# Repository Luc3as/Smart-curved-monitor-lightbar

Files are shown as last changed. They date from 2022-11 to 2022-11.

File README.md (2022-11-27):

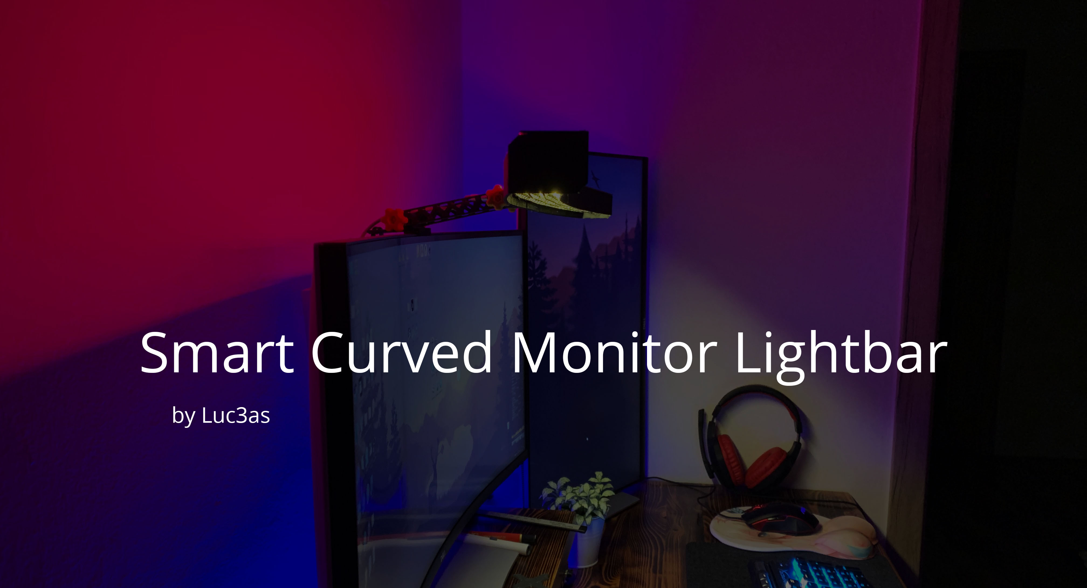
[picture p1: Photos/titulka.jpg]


## Idea behind this project

Custom made light bar, with easy connectivity and controllability from any home automation system. 
Integrated dual CCT light strip, to set just right color of light by time of day or type of task doing under the light. 
Backlight providing custom non disruptive mood light, with advanced effects possible thanks to individually addressable light strip. 
Everything powered from single USB-C 5V connector.

Universal attachment arms with adjustable height and angle for different monitor types.

## Designing the lightbar
Main goal here was to find a way and arrangement of led strip to provide light shining to desk, but without glaring into users’ eyes sitting behind the desk or casting light glares on monitor. I did some tests, measurements, came up with different lamp body designs, after few versions I came up with good solutions to satisfy those needs.  
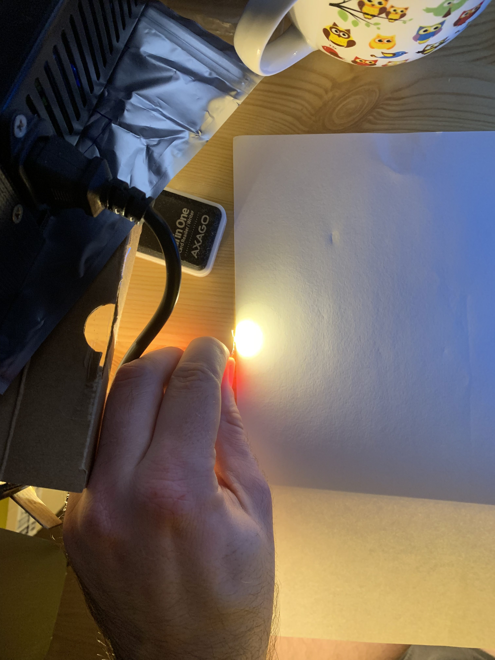
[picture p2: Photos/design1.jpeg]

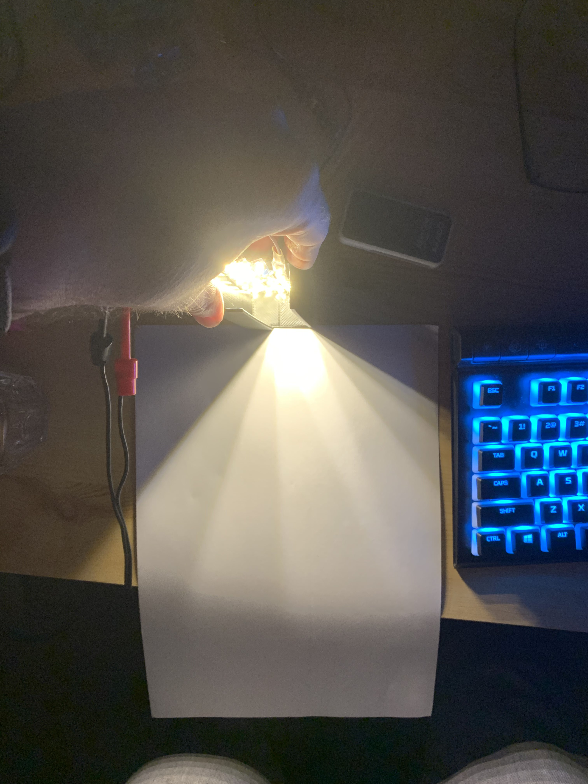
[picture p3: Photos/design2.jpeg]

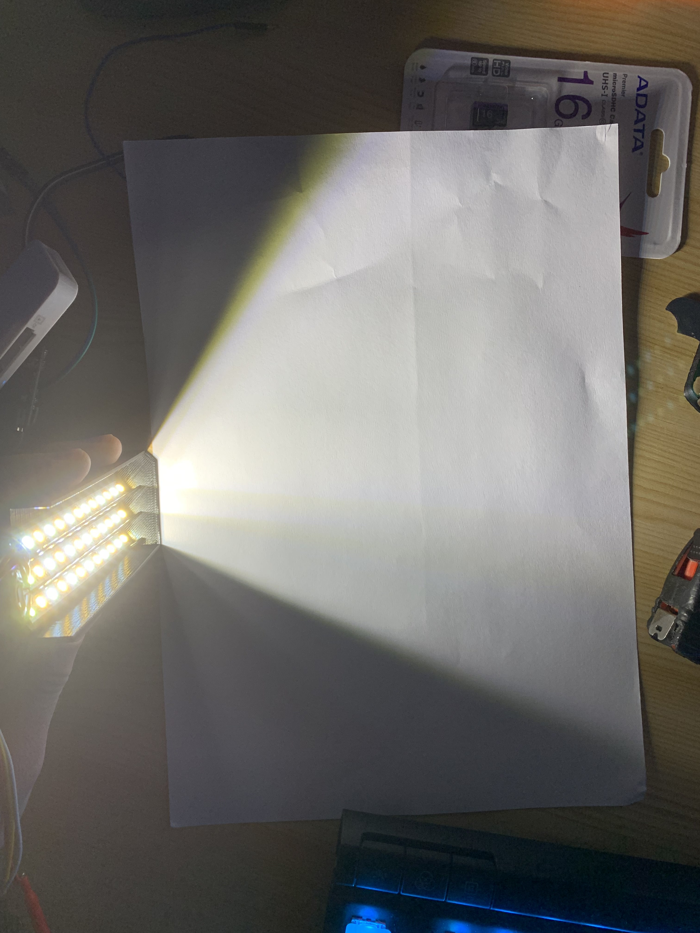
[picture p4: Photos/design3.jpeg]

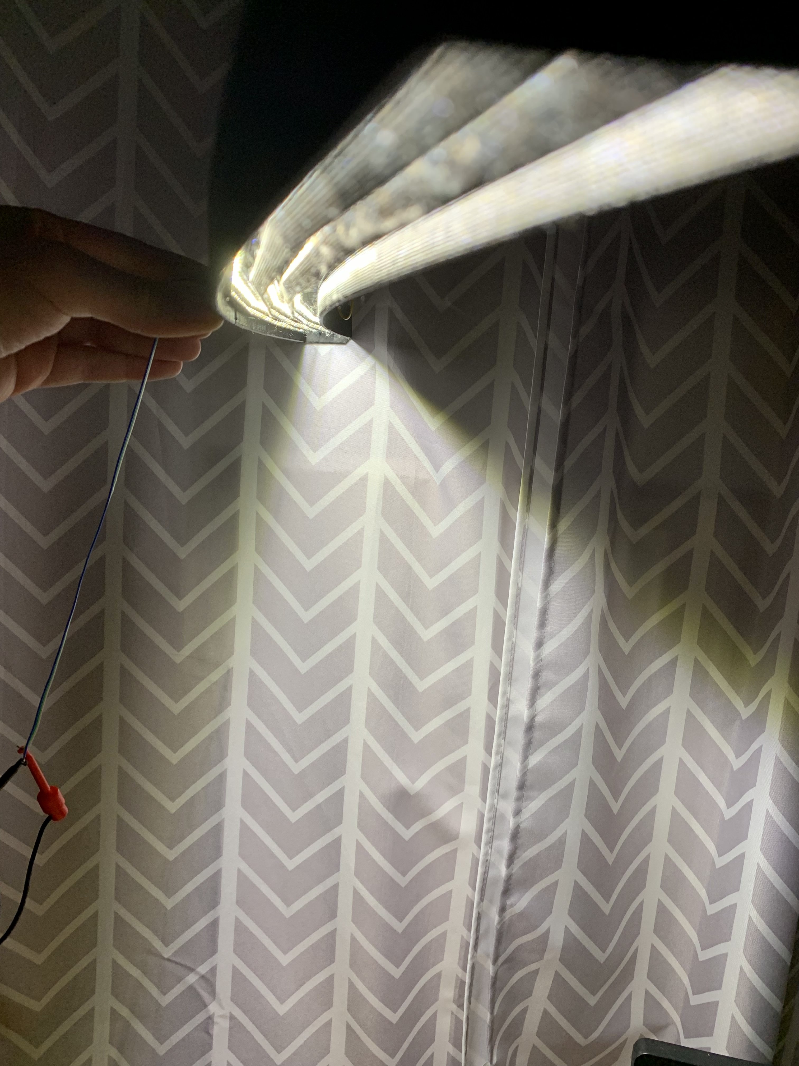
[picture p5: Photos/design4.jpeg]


## Printing and assembling

As material I picked PETG, but PLA would be OK too.

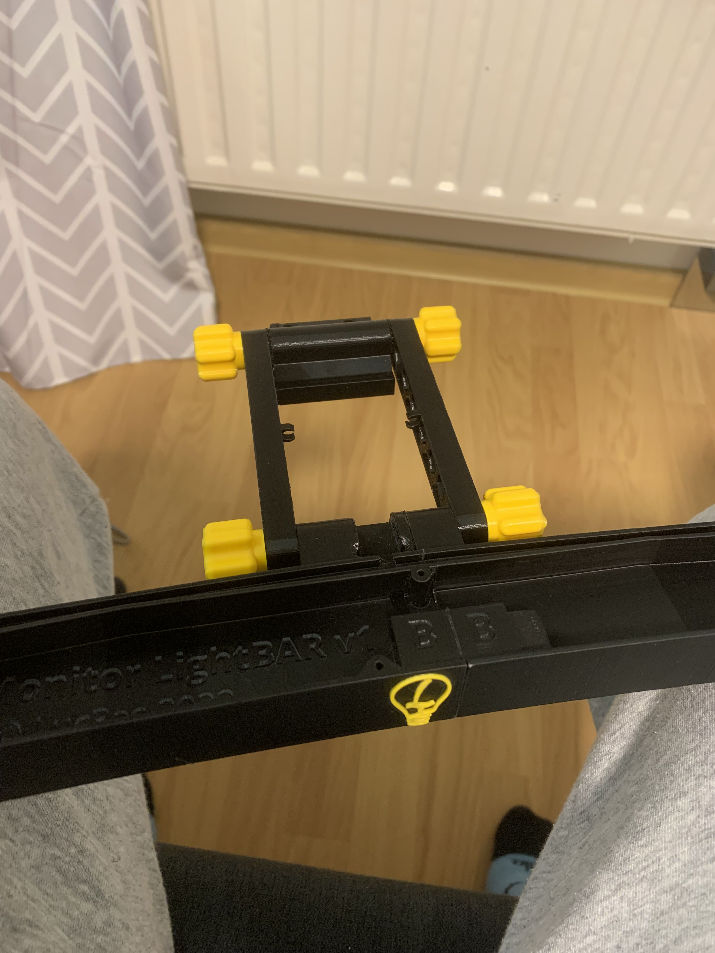
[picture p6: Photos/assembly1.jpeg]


Parts was designed to fit on standard size 3D printer

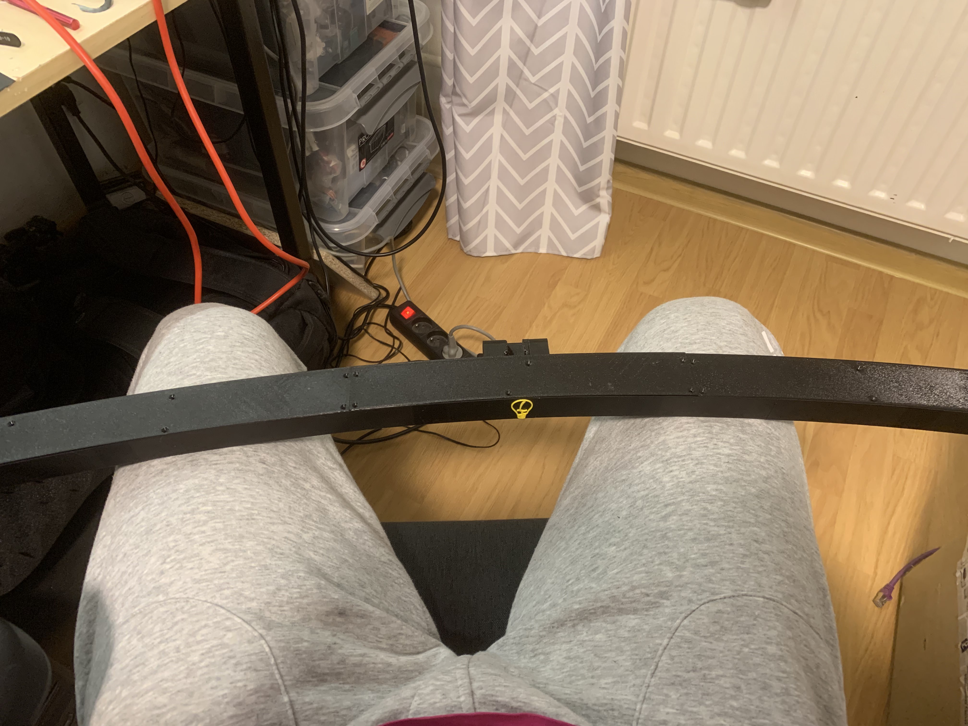
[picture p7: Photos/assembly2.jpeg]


Parts which will hold some mechanical load was designed for mechanical 3D inserts. 

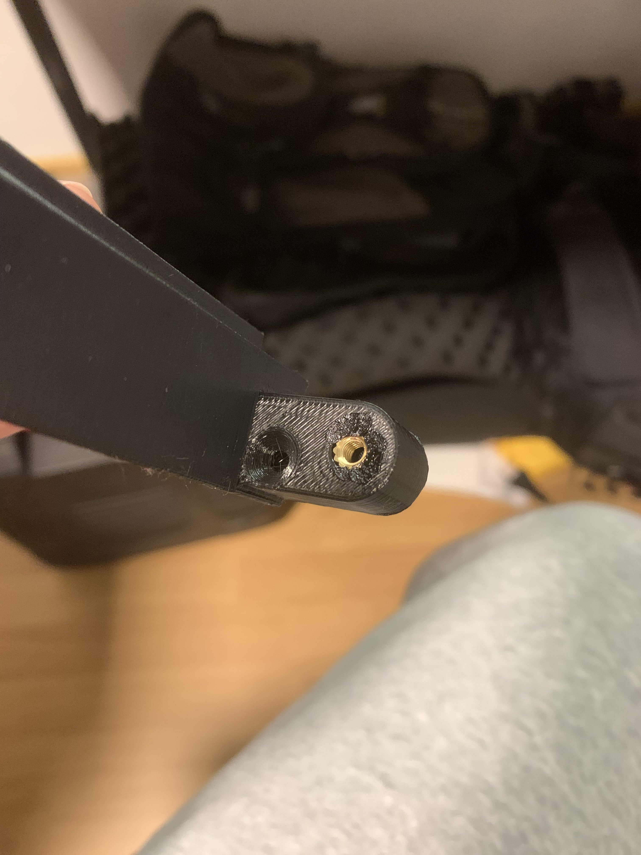
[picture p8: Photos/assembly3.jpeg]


## LEDs and electronics

I used dual CCT light strip powered by 5V, and WS2812b LED strip for backlight. Electronics is very simplistic, main controller is Wemos D1 mini, and 5V USB-C female connector board. There is no physical button for controlling the light as I will use home automation to control it. However, there are free pins on ESP8266 so some buttons or motion sensors could be easily installed in covers. 
To drive 2 white channels of LEDs I used simple connection of 2 N-Mosfet transistors to the outputs of ESP8266. Data pin of RGB led strip was connected right to the ESP8266. 

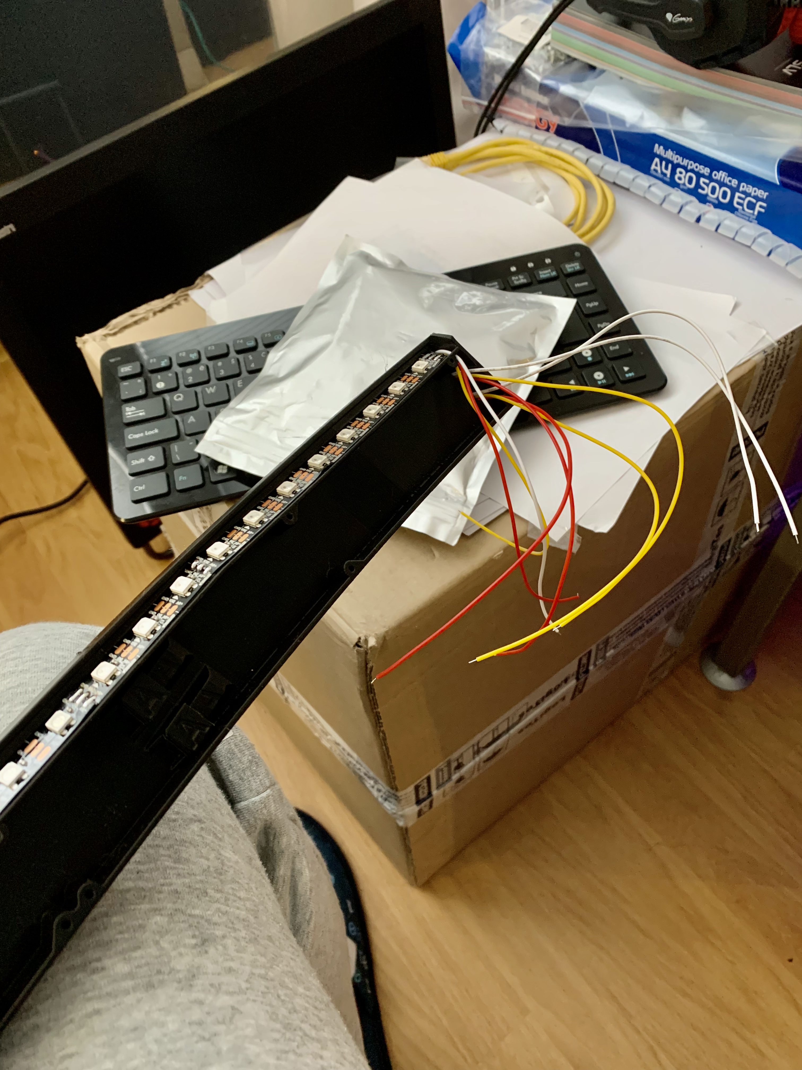
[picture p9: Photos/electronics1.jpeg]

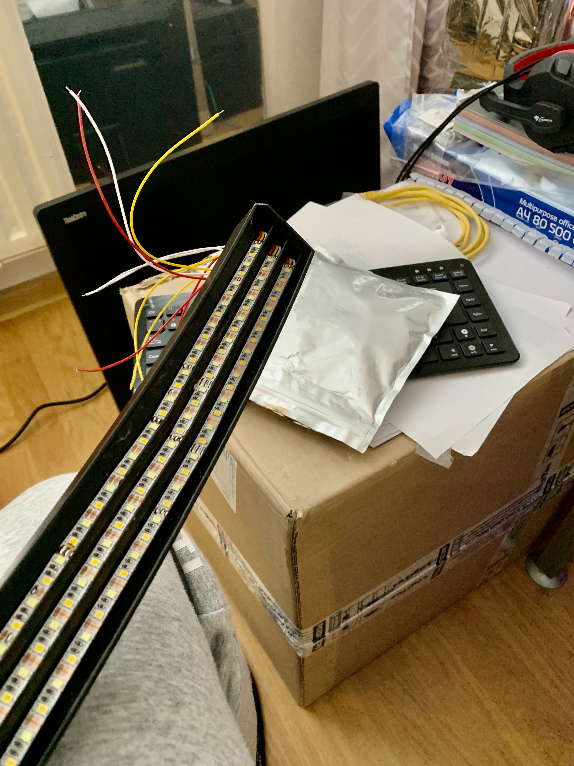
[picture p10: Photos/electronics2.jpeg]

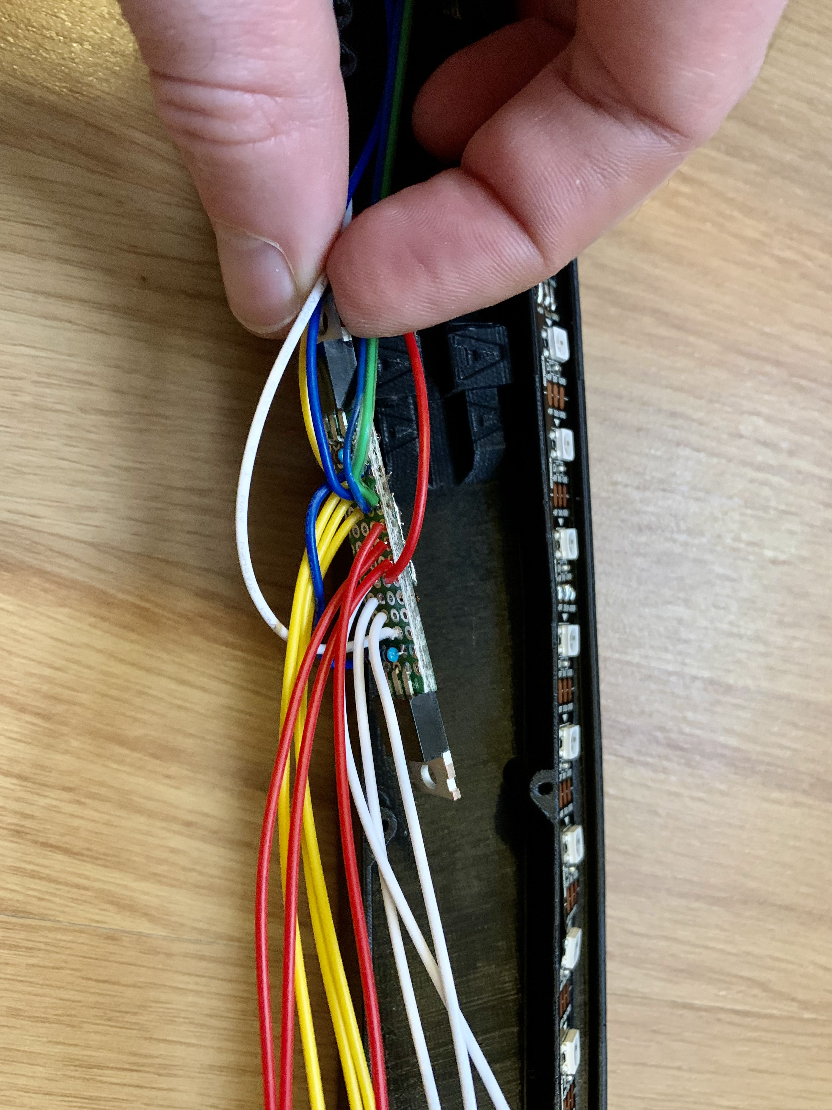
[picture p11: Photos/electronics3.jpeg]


## Firmware 

For firmware I used ESPHOME, you can find config in firmware.yaml

## Final installation

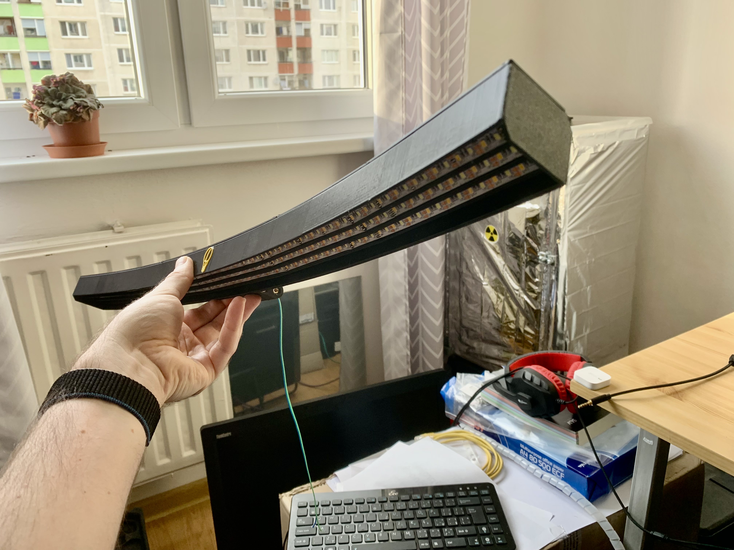
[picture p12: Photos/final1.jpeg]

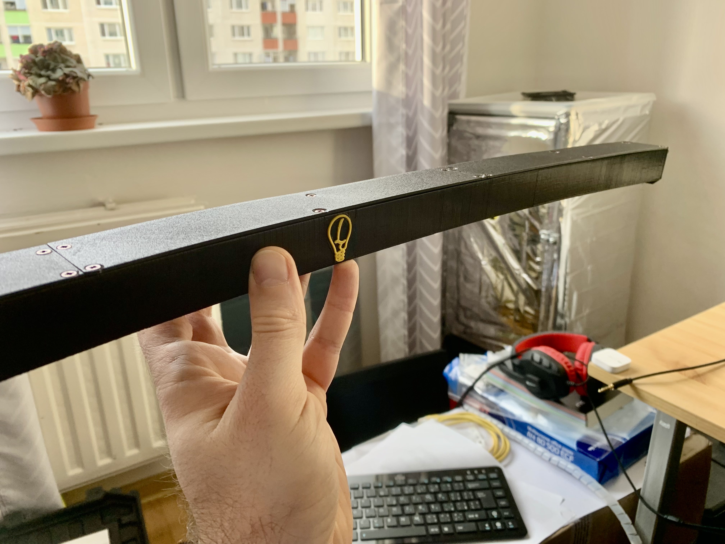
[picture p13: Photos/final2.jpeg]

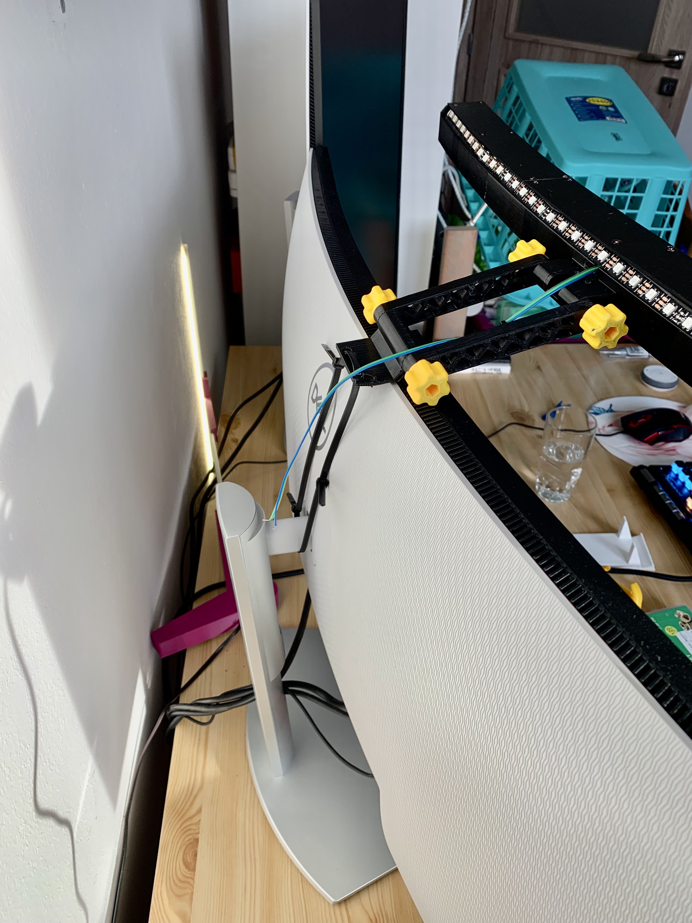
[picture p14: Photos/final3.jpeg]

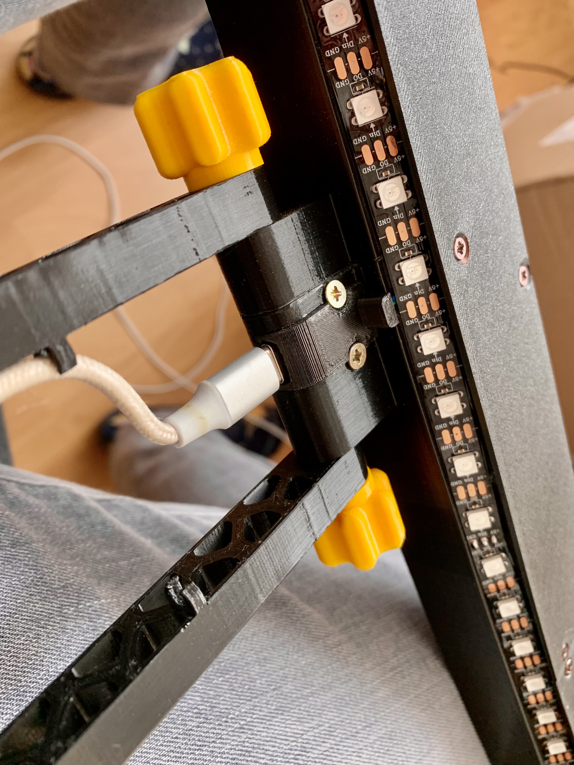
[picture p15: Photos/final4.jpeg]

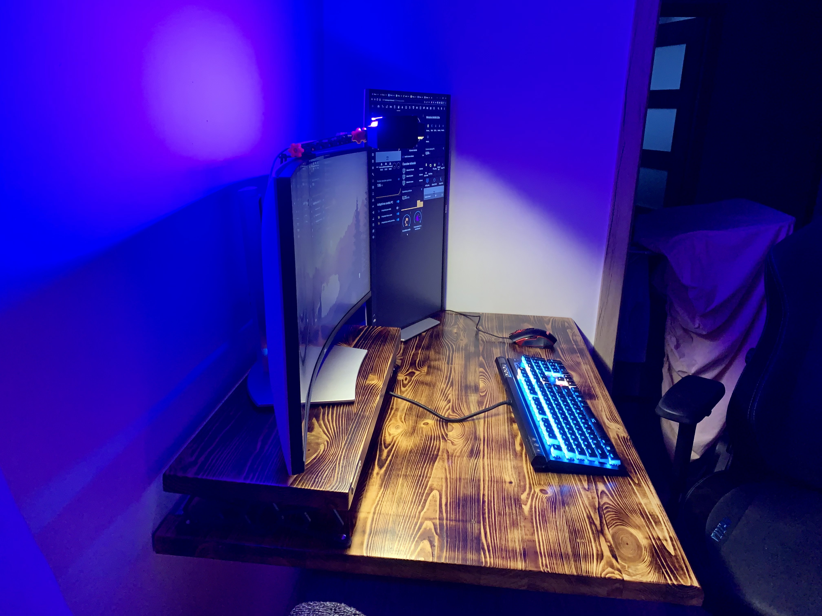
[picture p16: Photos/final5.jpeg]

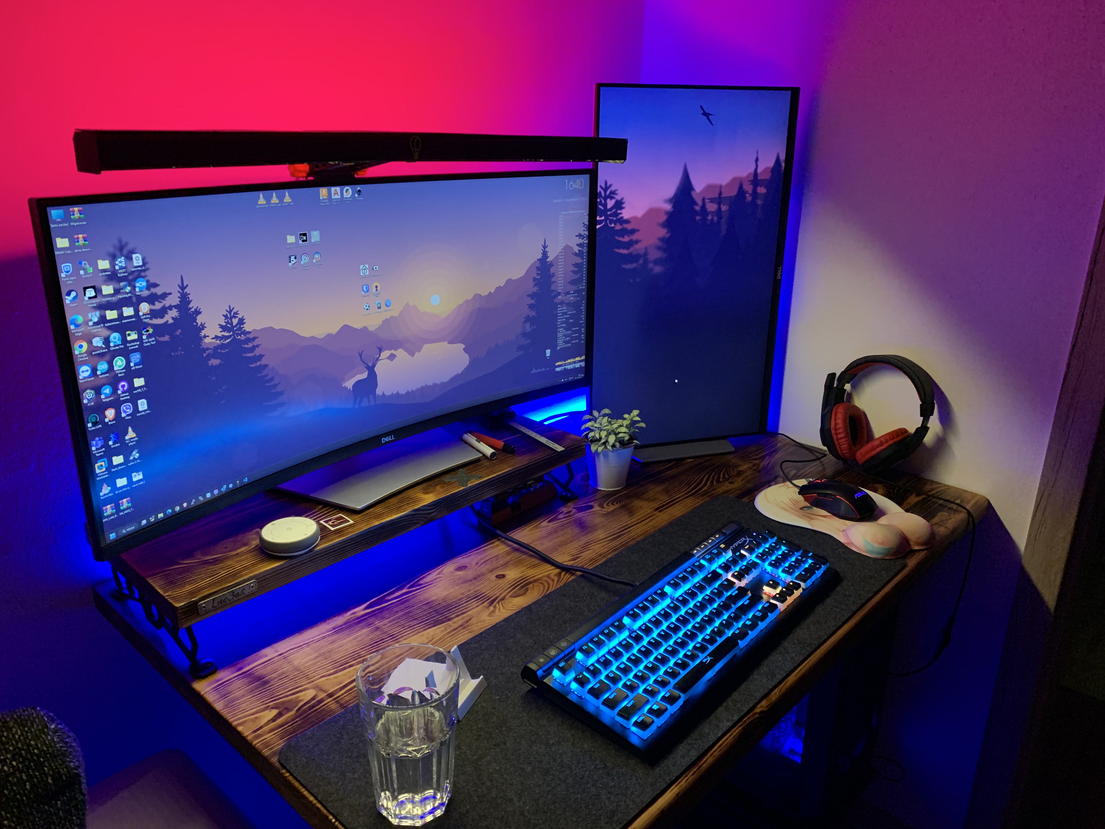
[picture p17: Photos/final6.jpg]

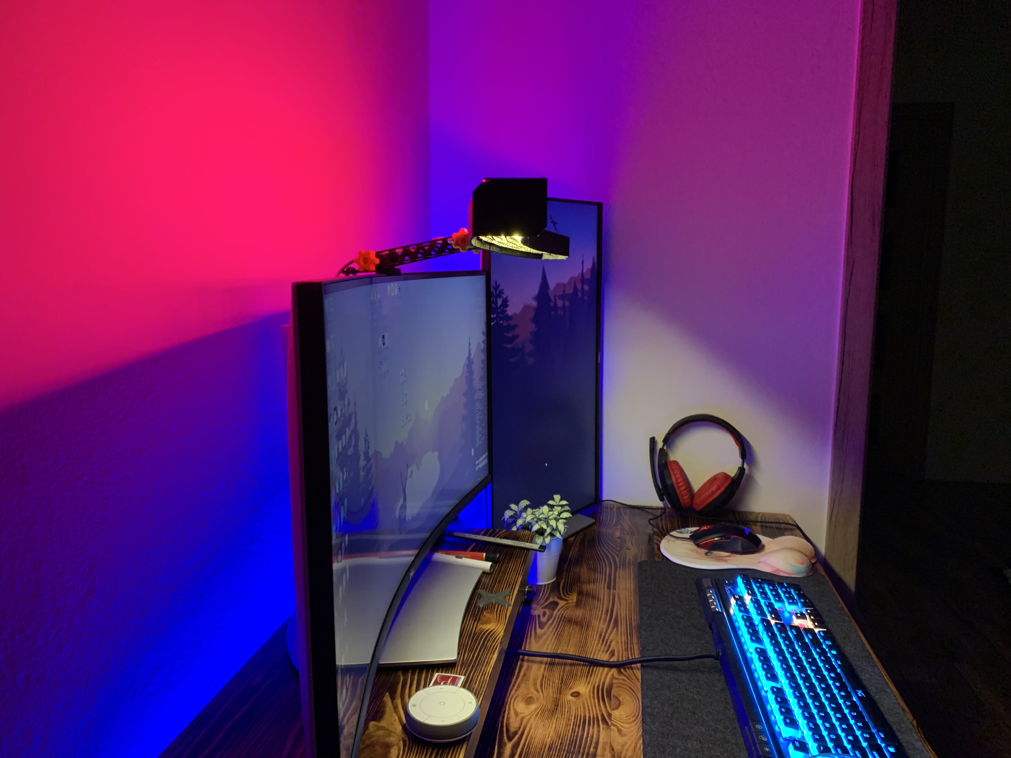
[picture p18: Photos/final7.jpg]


## Materials

* [Wemos D1 Mini](https://www.aliexpress.com/item/32831353752.html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)
* [USB-C female connector ](https://www.aliexpress.com/item/1005002795893679.html?spm=a2g0o.order_list.0.0.18751802bFIGnc)
* [Hot melt inserts ](https://www.aliexpress.com/item/1005003150553284.html?spm=a2g0o.order_list.0.0.18751802bFIGnc)
* [Dual CCT 5V LED Strip](https://www.aliexpress.com/item/1005001729120581.html?spm=a2g0o.order_list.0.0.18751802bFIGnc)
* [WS2812b RGB LED Strip](https://www.aliexpress.com/item/1005002890783311.html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)
* [IRFZ44N MOSFET Transistor](https://www.aliexpress.com/item/1005004930806422.html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)

## If you liked my work, you could buy me a coffee :)

<a class="" target="_blank" href="https://www.buymeacoffee.com/luc3as">Buy Me A Coffee</a>

### Or send some crypto

<a class="" target="_blank" href="https://lukasporubcan.sk/donate">Donate Bitcoin</a>

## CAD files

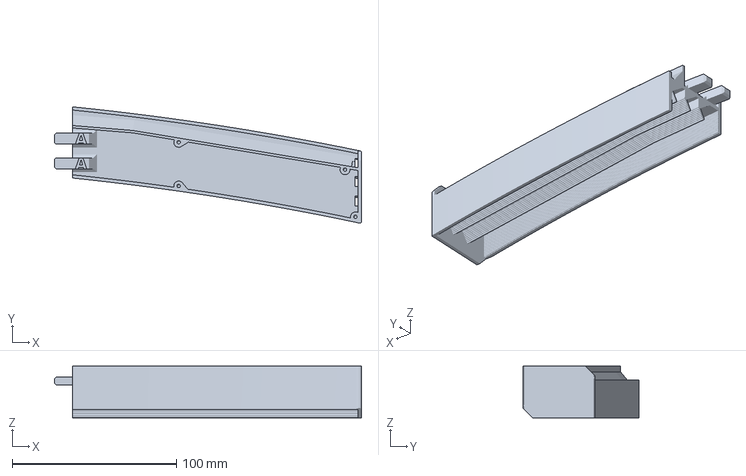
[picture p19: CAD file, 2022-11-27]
3D-files/Lamp body 1.3mf
186.6 x 70.7 x 31.5 mm

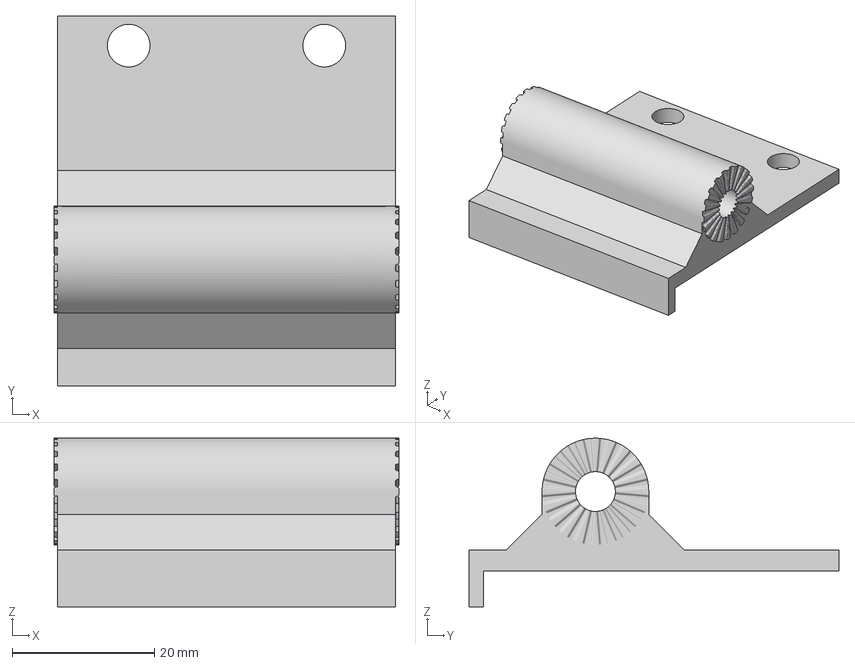
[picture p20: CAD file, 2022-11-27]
3D-files/Monitor base.3mf
48.5 x 52.0 x 23.7 mm

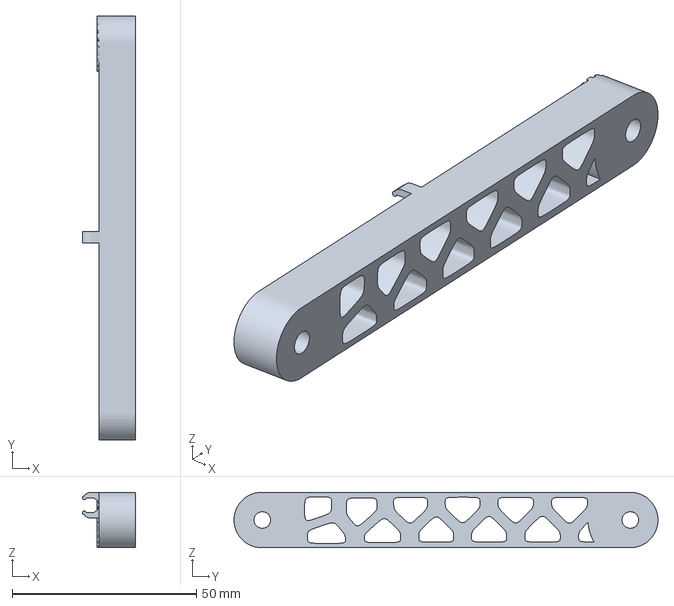
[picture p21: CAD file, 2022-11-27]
3D-files/Arm right.3mf
14.5 x 115.0 x 15.0 mm

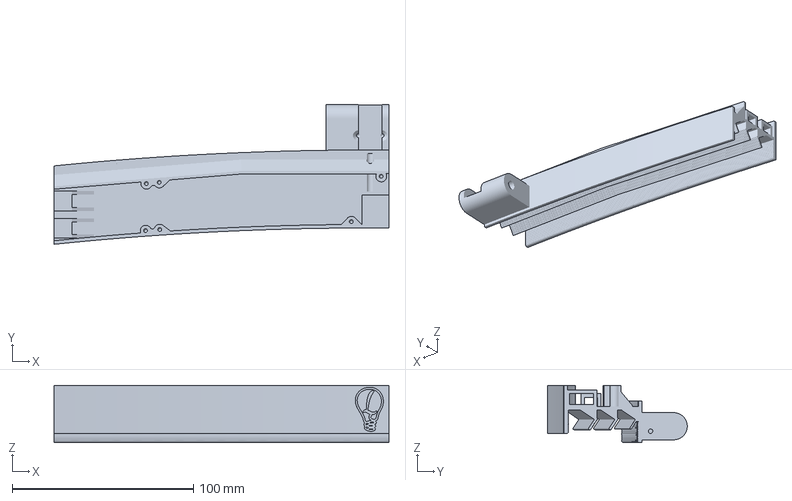
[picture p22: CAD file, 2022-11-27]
3D-files/Lamp body 4.3mf
185.0 x 77.1 x 31.5 mm

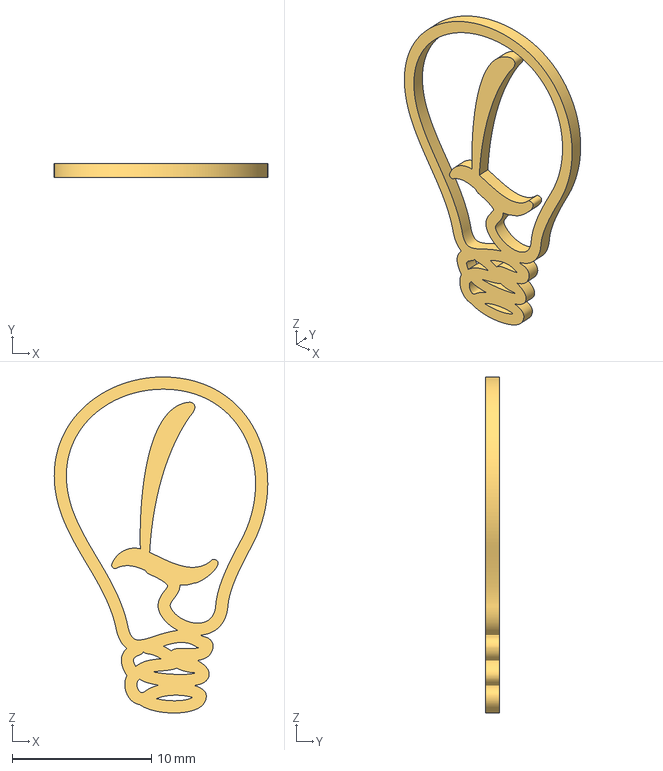
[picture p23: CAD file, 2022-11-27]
3D-files/Lamp logo.3mf
15.3 x 1.00 x 24.1 mm

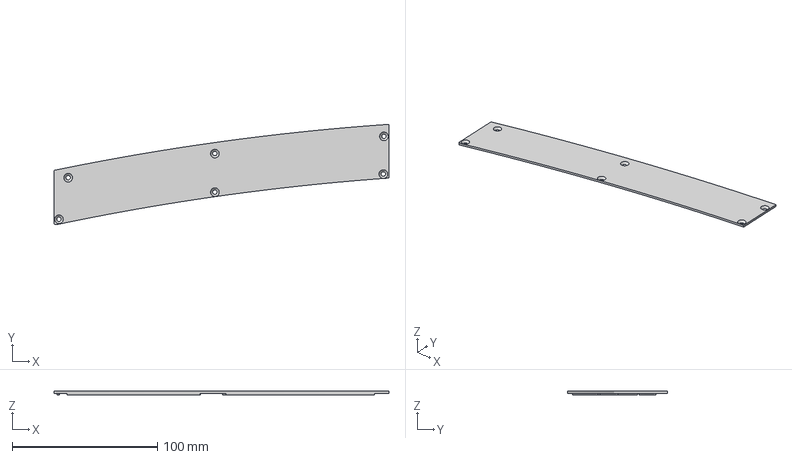
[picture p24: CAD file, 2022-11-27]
3D-files/Top cover 3.3mf
230.9 x 69.2 x 2.50 mm

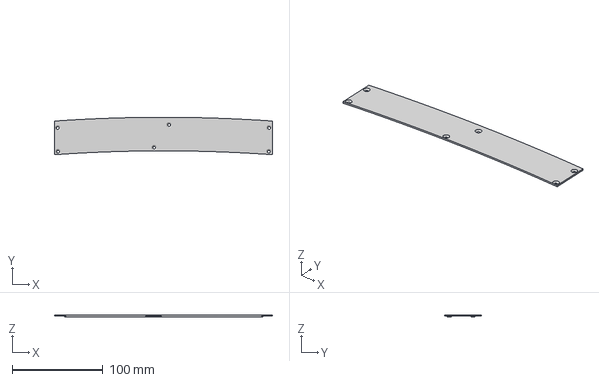
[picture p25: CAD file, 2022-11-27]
3D-files/Top cover 2.3mf
240.0 x 41.2 x 2.50 mm

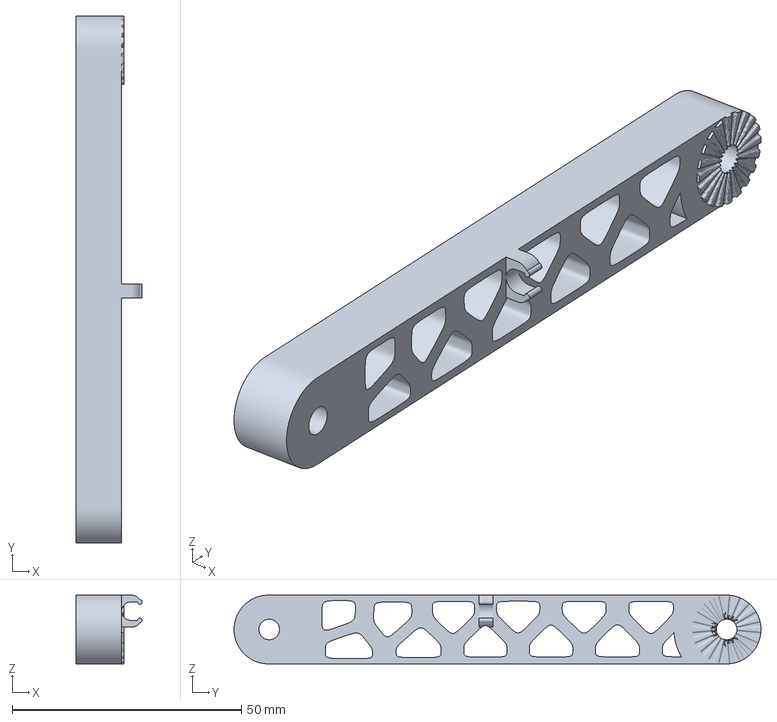
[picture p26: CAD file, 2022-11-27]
3D-files/Arm left.3mf
14.5 x 115.0 x 15.0 mm

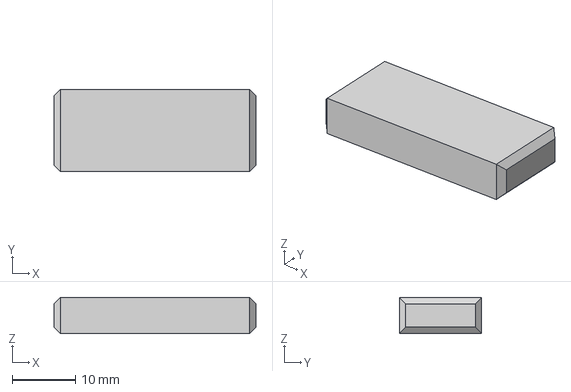
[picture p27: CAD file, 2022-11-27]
3D-files/center pin 2x.3mf
32.0 x 13.1 x 5.70 mm

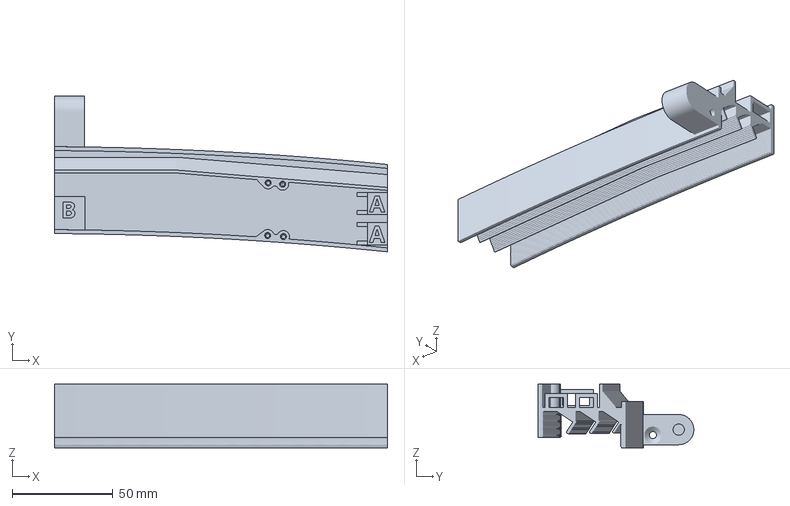
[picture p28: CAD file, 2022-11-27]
3D-files/Lamp body 2.3mf
165.0 x 77.2 x 31.5 mm

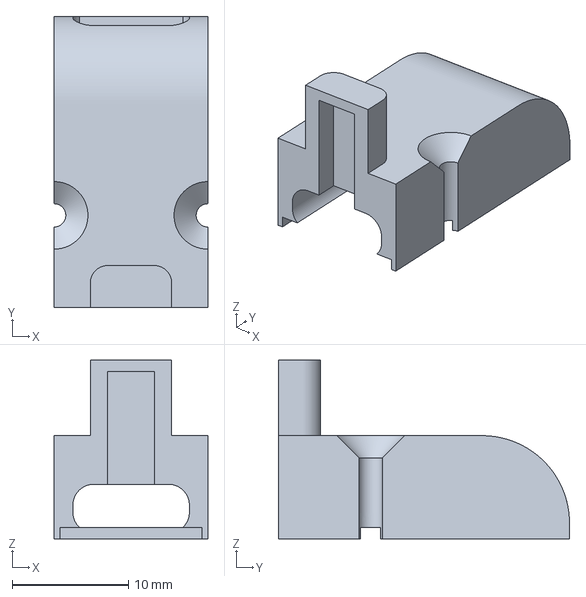
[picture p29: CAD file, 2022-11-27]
3D-files/USB port cover.3mf
13.2 x 25.0 x 15.4 mm

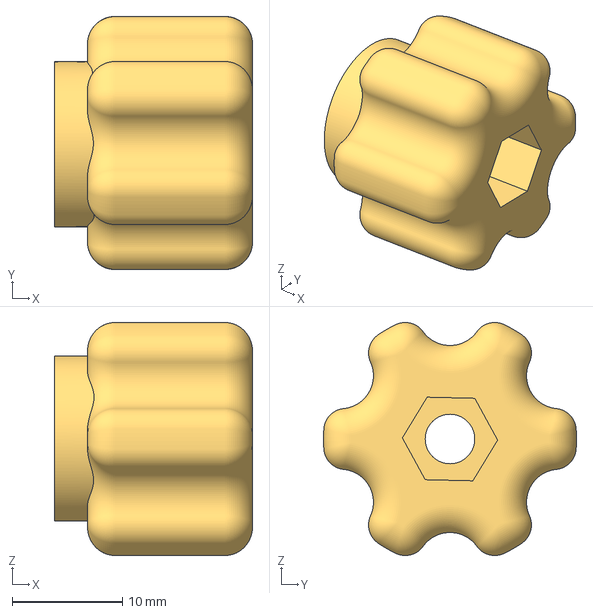
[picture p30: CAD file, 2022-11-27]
3D-files/Nut 2x.3mf
18.0 x 23.0 x 21.2 mm

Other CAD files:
3D-files/Lamp body 3.3mf
3D-files/Top cover 1.3mf

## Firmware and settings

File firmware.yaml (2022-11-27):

substitutions:
  devicename: "monitor-lightbar"
  upper_devicename: "Lampa PC"

esphome:
  name: $devicename
  platform: ESP8266
  board: d1_mini

wifi:
  networks:
  - ssid: !secret wifi_ssid
    password: !secret wifi_password

# Enable fallback hotspot (captive portal) in case wifi connection fails
  ap:
    ssid: ${upper_devicename} Hotspot
    password: !secret esphome_fallback_ap_pass

captive_portal:

# Enable logging
logger:
# level: debug

# Enable Home Assistant API
# Enable Home Assistant API
api:
  password: !secret esphome_api_pass

ota:
  password: !secret esphome_ota_pass
    
web_server:
  port: 80
  auth:
    username: admin
    password: "pass"
    
    
light:
  - platform: neopixelbus
    name: "Podsvietenie monitor"
    type: GRB
    pin: GPIO3
    num_leds: 41
    variant: WS2812
    effects:
      - addressable_rainbow:
      - addressable_color_wipe:
      - addressable_scan:
      - addressable_flicker:
    
  - platform: cwww
    name: "Svetlo PC"
    cold_white: cold_white
    warm_white: warm_white
    cold_white_color_temperature: 6536 K
    warm_white_color_temperature: 2000 K
    constant_brightness: false

output:    
  - platform: esp8266_pwm
    id: warm_white
    pin: D6

  - platform: esp8266_pwm
    id: cold_white
    pin: D7
